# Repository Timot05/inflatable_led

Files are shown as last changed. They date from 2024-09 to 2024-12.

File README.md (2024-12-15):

# A portable light printed using Rapid Liquid Printing

## Specs

- 2700K
- About 400 lumens
- Dimmable
- Rechargeable
- Flashes when battery low

## Implementation

- Micro: RP2040
- LED Driver: TPS61165
- LED: OSRAM GW JTLPS1.EM-KKLL-XX58-1
- Batteries: TBD
- Battery charger: TBD

## TODOs for V1 order:

- Check order of LEDs
- Check the caps footprint
- C15, C16 are wrong size
- Remove todo from schematic

## TODOs for v2:

- [x] Add charging status to micro
- [x] fix the led circuit switching
- [x] enable low power mode with reset switch (no long press. How did we switch all circuits on mopi?)
- [x] Remove the cap on qspi_ss
- [x] DNP for the 3.3V led
- [x] Add a buck boost instead of ldo -> Remain with LDO but remove shotky diode (need to add it in case?)
- [x] Check the bat sense feature - probs ok
- [x] White circuit for reflection - will do
- [ ] Add gnd, vref, 3.3V to the debug port
- [x] Add the 10k resistor to the TS pin on the charger -> changed charger and fixed TS
- [x] Switch to ULDO
- [x] Change the battery holder -> changed to double battery holder

Nice to have:

- i2c connected charger
- Protrude the button more
- Nice feeling button

## TODOs for V3

- [ ] add a label for +/- battery
- [ ] remove the pullup on the on/off bt
- [ ] add a blinky led

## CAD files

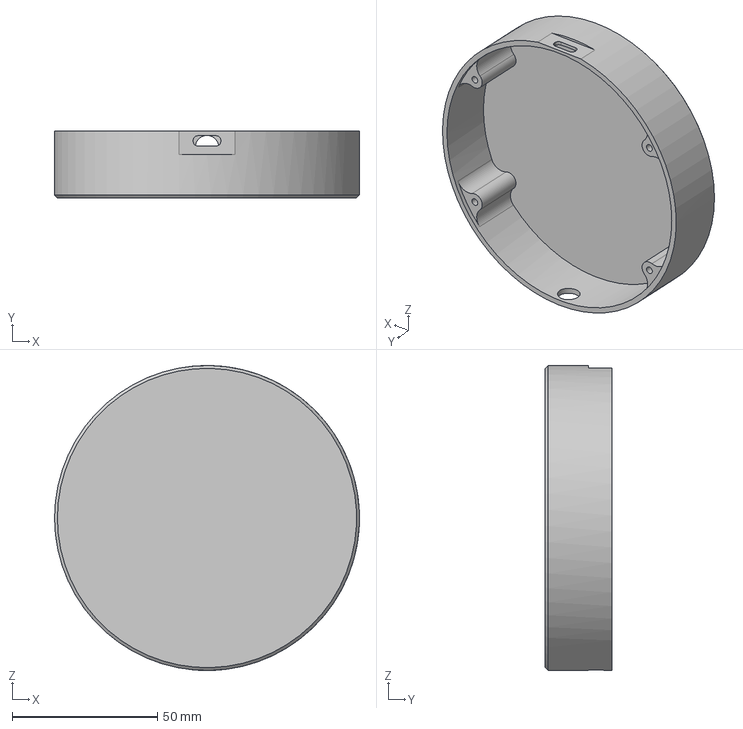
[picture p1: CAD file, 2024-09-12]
meca/Enclosure.step
105.0 x 23.0 x 105.0 mm

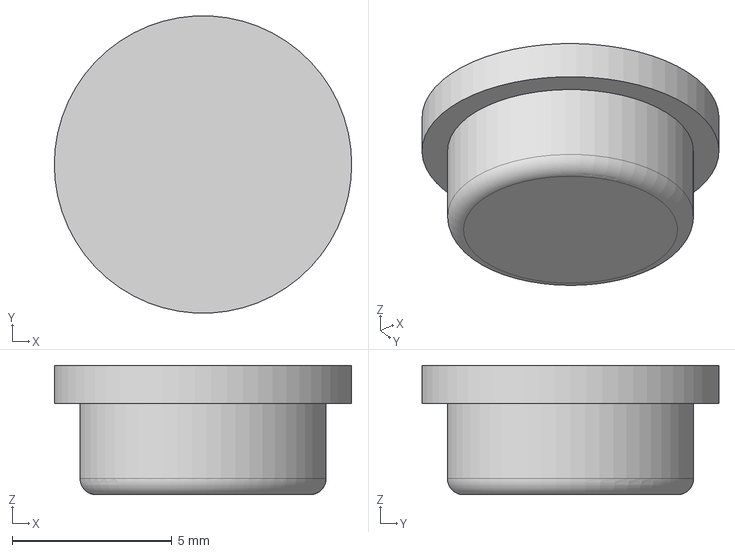
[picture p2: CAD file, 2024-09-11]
meca/Button.step
9.30 x 9.29 x 4.05 mm

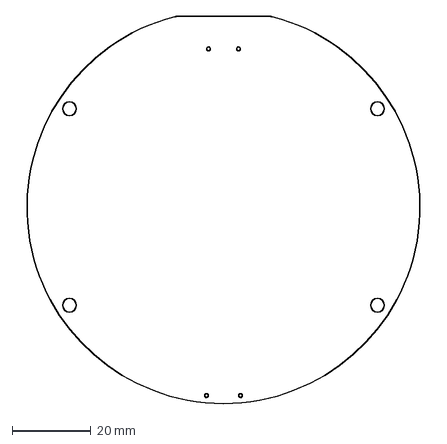
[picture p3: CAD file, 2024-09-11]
meca/PCB_outline.dxf
105.5 x 98.5 mm

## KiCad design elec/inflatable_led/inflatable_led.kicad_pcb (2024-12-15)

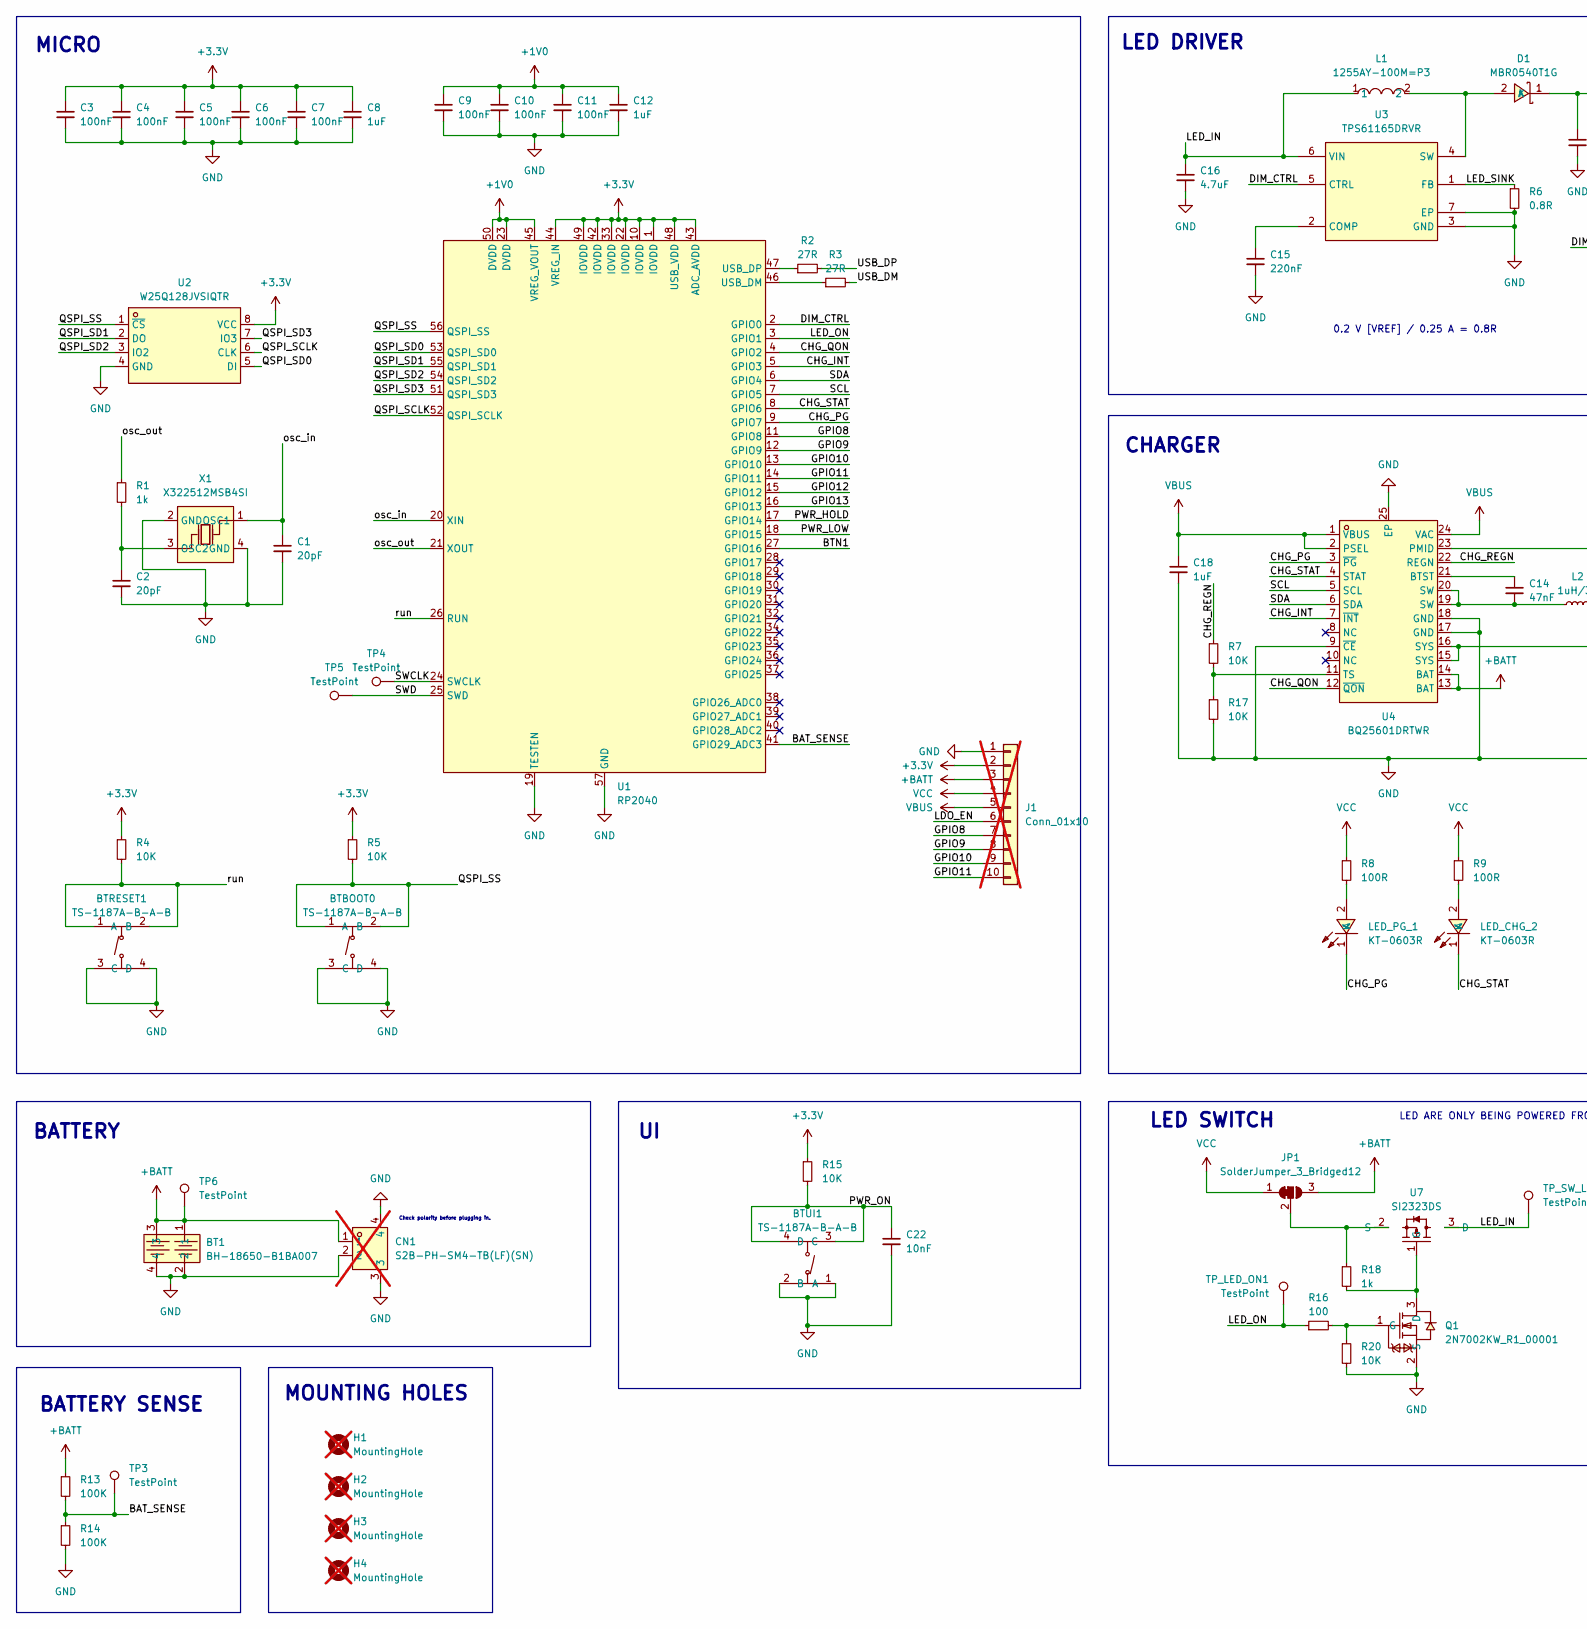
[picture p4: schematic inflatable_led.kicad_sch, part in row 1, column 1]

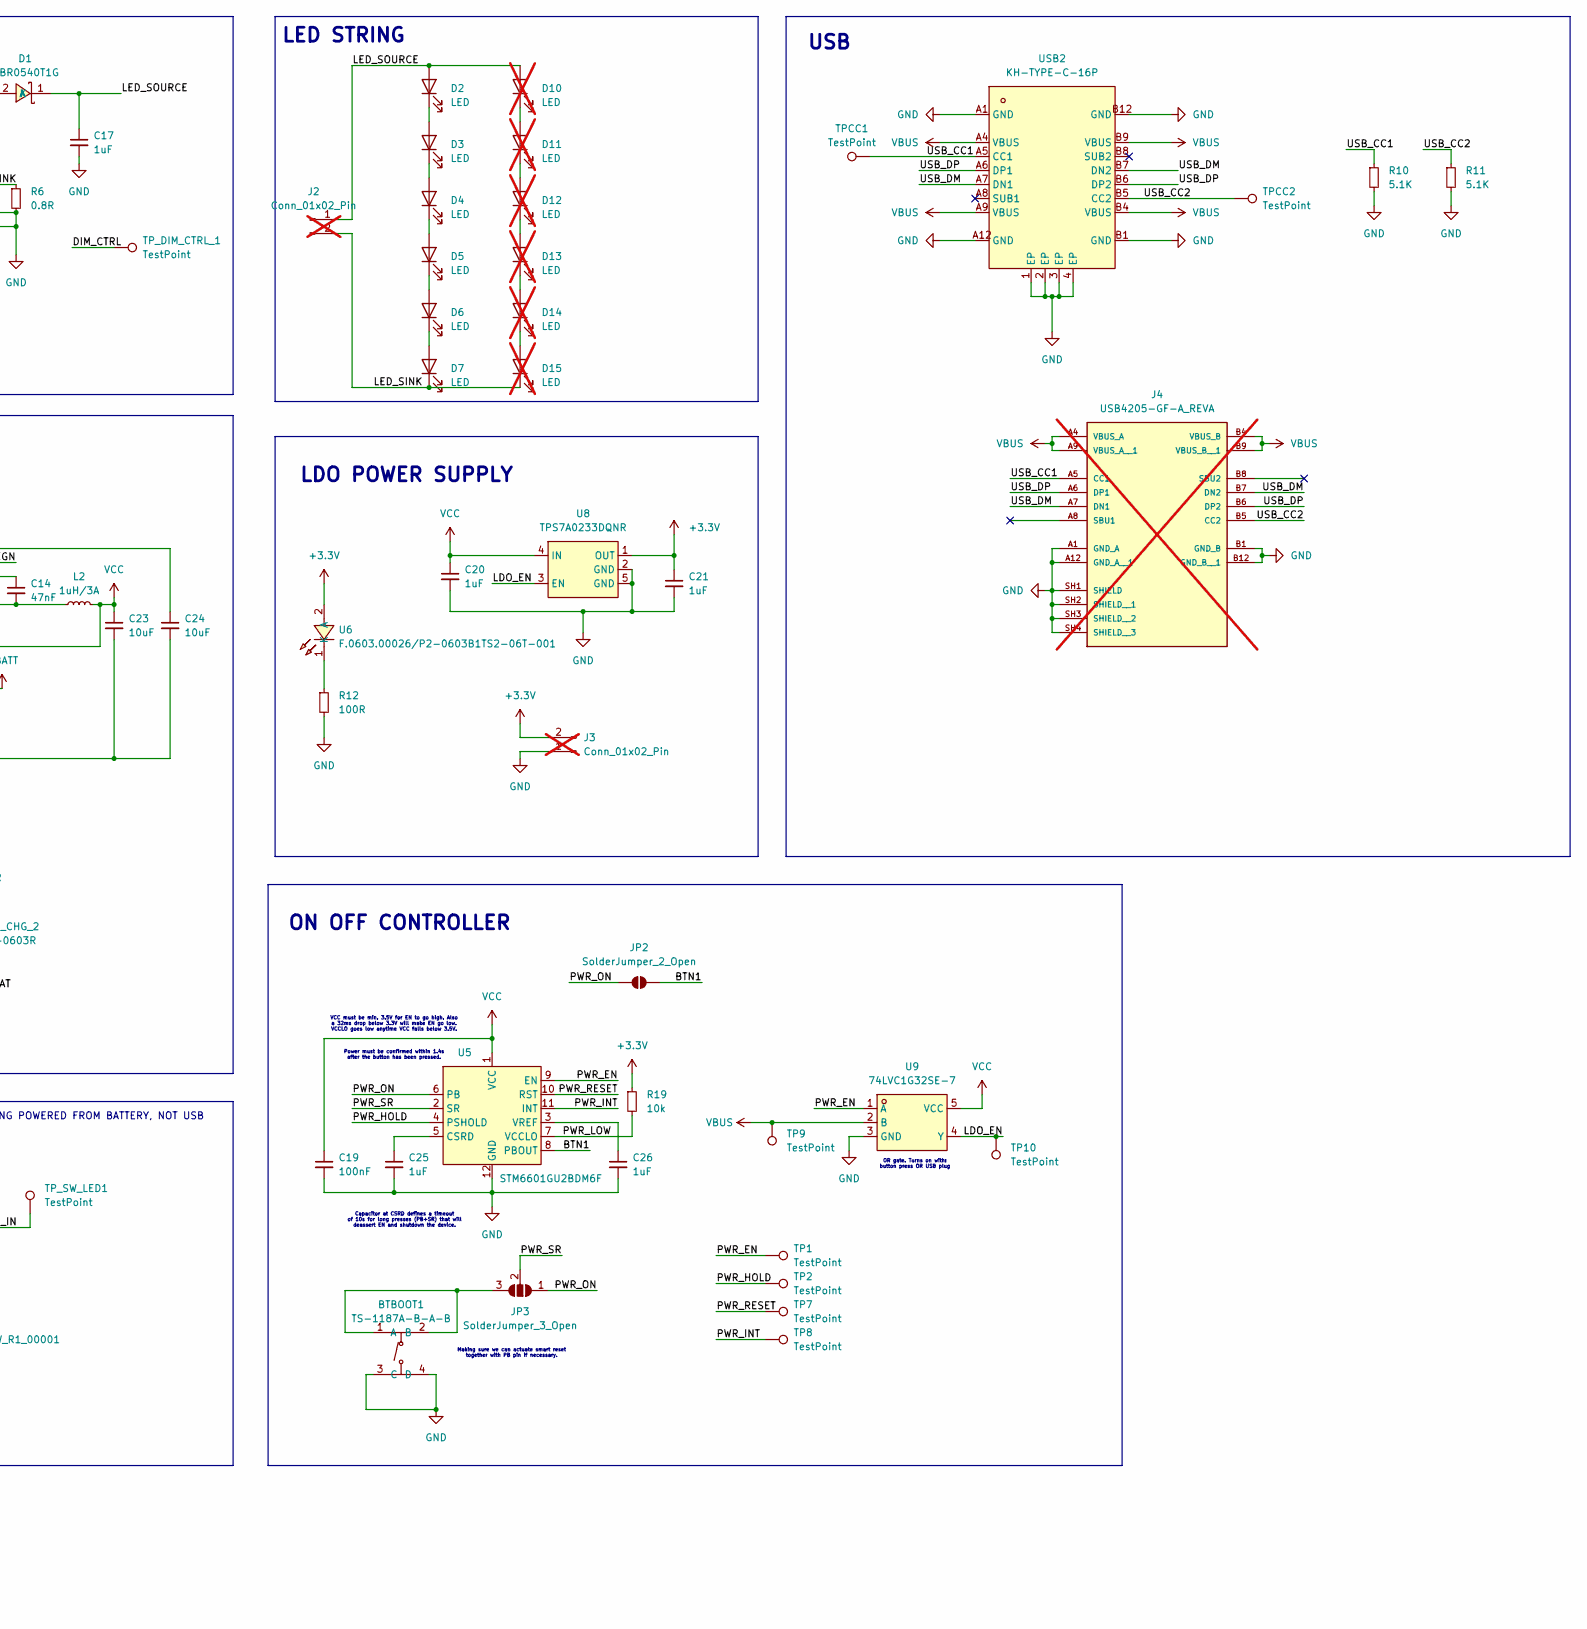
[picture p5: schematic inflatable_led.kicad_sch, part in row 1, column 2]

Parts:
BT1: BH-18650-B1BA007; BAT-SMD_BH-18650-B1BA007; LCSC Part C6937126
BTBOOT0, BTBOOT1: TS-1187A-B-A-B; SW-SMD_4P-L5.1-W5.1-P3.70-LS6.5-TL-2; LCSC Part C318884
BTRESET1: TS-1187A-B-A-B; SW-SMD_4P-L5.1-W5.1-P3.70-LS6.5-TL-2; LCSC Part C318884
BTUI1: TS-1187A-B-A-B; SW-SMD_4P-L5.1-W5.1-P3.70-LS6.5-TL-2; LCSC Part C318884
C1, C2: 20pF; C_0402_1005Metric; LCSC Part C1554
C3, C4, C5, C6, C7, C9, C10, C11: 100nF; C_0402_1005Metric; LCSC Part C1525
C8, C12, C17, C18, C20, C21: 1uF; C_0805_2012Metric; LCSC Part C28323
C14: 47nF; C_0402_1005Metric; Digikey 311-1801-1-ND
C15: 220nF; C_0402_1005Metric; LCSC Part C16772
C16: 4.7uF; C_0402_1005Metric; LCSC Part C23733
C19: 100nF; C_0402_1005Metric; Digikey 311-1776-1-ND
C22: 10nF; C_0402_1005Metric; LCSC Part C15195
C23, C24: 10uF; C_0805_2012Metric; LCSC Part C15850
C25, C26: 1uF; C_0805_2012Metric; Digikey 311-1444-1-ND
CN1: S2B-PH-SM4-TB(LF)(SN); CONN-SMD_P2.00_S2B-PH-SM4-TB-LF-SN; LCSC Part C295747; not fitted
D1: MBR0540T1G; SOD-123_L2.8-W1.8-LS3.7-RD; LCSC Part C109213
D2, D3, D4, D5, D6, D7: LED; GW JTLPS1EM; LCSC Part C5220764
D10: LED; GW JTLPS1EM; LCSC Part C5220764; not fitted
D11, D12, D13, D14, D15: LED; GW JTLPS1EM; not fitted
H1, H2, H3, H4: MountingHole; MountingHole_3.2mm_M3_Pad_Via; not fitted
J1: Conn_01x10; PinHeader_1x10_P1.00mm_Vertical; not fitted
J2, J3: Conn_01x02_Pin; PinHeader_1x02_P2.54mm_Vertical; not fitted
J4: USB4205-GF-A_REVA; GCT_USB4205-GF-A_REVA; PARTREV A; not fitted
JP1: SolderJumper_3_Bridged12; SolderJumper-3_P1.3mm_Bridged12_RoundedPad1.0x1.5mm
JP2: SolderJumper_2_Open; SolderJumper-2_P1.3mm_Open_TrianglePad1.0x1.5mm
JP3: SolderJumper_3_Open; SolderJumper-3_P2.0mm_Open_TrianglePad1.0x1.5mm
L1: 1255AY-100M=P3; IND-SMD_L6.0-W6.0; LCSC Part C160950
L2: 1uH/3A; L_1008_2520Metric; Digikey 1276-6929-1-ND
LED_CHG_2: KT-0603R; LED0603-RD; LCSC Part C2286
LED_PG_1: KT-0603R; LED0603-RD; LCSC Part C2286
Q1: 2N7002KW_R1_00001; SOT-323-3_L2.0-W1.3-P1.30-LS2.1-BR; LCSC Part C313495
R1, R18: 1k; R_0402_1005Metric; LCSC Part C11702
R2, R3: 27R; R_0402_1005Metric; LCSC Part C25100
R4, R5, R7, R15, R17, R20: 10K; R_0402_1005Metric; LCSC Part C25744
R6: 0.8R; R_0805_2012Metric_Pad1.20x1.40mm_HandSolder; LCSC Part C175720
R8, R9, R12: 100R; R_0402_1005Metric; LCSC Part C25076
R10, R11: 5.1K; R_0402_1005Metric; LCSC Part C25905
R13, R14: 100K; R_0402_1005Metric; LCSC Part C25741
R16: 100; R_0402_1005Metric; LCSC Part C25076
R19: 10k; R_0402_1005Metric; Digikey 311-10.0KHRCT-ND
TP1, TP2, TP7, TP8, TP9, TP10: TestPoint; TestPoint_Pad_D1.0mm
TP3, TP4, TP5, TP6: TestPoint; TestPoint_Pad_D1.5mm
TPCC1, TPCC2: TestPoint; TestPoint_Pad_D1.5mm
TP_DIM_CTRL_1: TestPoint; TestPoint_Pad_D1.5mm
TP_LED_ON1: TestPoint; TestPoint_Pad_D1.5mm
TP_SW_LED1: TestPoint; TestPoint_Pad_D1.5mm
U1: RP2040; LQFN-56_L7.0-W7.0-P0.4-EP; LCSC Part C2040
U2: W25Q128JVSIQTR; SOIC-8_L5.3-W5.3-P1.27-LS8.0-BL; LCSC Part C97521
U3: TPS61165DRVR; WSON-6_L2.0-W2.0-P0.65-TL-EP; LCSC Part C122568
U4: BQ25601DRTWR; WQFN-24_L4.0-W4.0-P0.50-TL-EP2.7; LCSC Part C2859691
U5: STM6601GU2BDM6F; TDFN-12_2x3mm_P0.5mm; Digikey 497-14857-1-ND
U6: F.0603.00026/P2-0603B1TS2-06T-001; LED0603-RD; LCSC Part C7496819
U7: SI2323DS; SOT-23-3_L2.9-W1.3-P1.90-LS2.4-BR; LCSC Part C5182044
U8: TPS7A0233DQNR; X2SON-4_L1.0-W1.0-P0.65-TL-EP; LCSC Part C5220177
U9: 74LVC1G32SE-7; SOT-353_L2.0-W1.2-P0.65-LS2.1-BL; LCSC Part C460530
USB2: KH-TYPE-C-16P; USB-C-SMD_KH-TYPE-C-16P; LCSC Part C709357
X1: X322512MSB4SI; OSC-SMD_4P-L3.2-W2.5-BL; LCSC Part C9002

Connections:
+1V0: C9.1, C10.1, C11.1, C12.1, U1.23 (DVDD), U1.45 (VREG_VOUT), U1.50 (DVDD)
+3.3V: C3.1, C4.1, C5.1, C6.1, C7.1, C8.1, C21.1, J1.2, J3.2, R4.1, R5.1, R15.1, R19.1, U1.1 (IOVDD), U1.10 (IOVDD), U1.22 (IOVDD), U1.33 (IOVDD), U1.42 (IOVDD), U1.43 (ADC_AVDD), U1.44 (VREG_IN), U1.48 (USB_VDD), U1.49 (IOVDD), U2.8 (VCC), U6.2 (A), U8.1 (OUT)
+BATT: BT1.1, BT1.3, CN1.1, J1.3, JP1.3 (B), R13.1, TP6.1, U4.13 (BAT), U4.14 (BAT)
/BAT_SENSE: R13.2, R14.1, TP3.1, U1.41 (GPIO29_ADC3)
/BTN1: JP2.2 (B), U1.27 (GPIO16), U5.8 (PBOUT)
/CHG_INT: U1.5 (GPIO3), U4.7 (~INT)
/CHG_PG: LED_PG_1.1 (K), U1.9 (GPIO7), U4.3 (~PG)
/CHG_QON: U1.4 (GPIO2), U4.12 (~QON)
/CHG_REGN: R7.1, U4.22 (REGN)
/CHG_STAT: LED_CHG_2.1 (K), U1.8 (GPIO6), U4.4 (STAT)
/DIM_CTRL: TP_DIM_CTRL_1.1, U1.2 (GPIO0), U3.5 (CTRL)
/GPIO8: J1.7, U1.11 (GPIO8)
/GPIO9: J1.8, U1.12 (GPIO9)
/GPIO10: J1.9, U1.13 (GPIO10)
/GPIO11: J1.10, U1.14 (GPIO11)
/GPIO12: U1.15 (GPIO12)
/GPIO13: U1.16 (GPIO13)
/LDO_EN: J1.6, TP10.1, U8.3 (EN), U9.4 (Y)
/LED_IN: C16.1, L1.1, TP_SW_LED1.1, U3.6 (VIN), U7.3 (D)
/LED_ON: R16.1, TP_LED_ON1.1, U1.3 (GPIO1)
/LED_SINK: D7.1 (K), D15.1 (K), J2.2, R6.1, U3.1 (FB)
/LED_SOURCE: C17.1, D1.1 (K), D2.2 (A), D10.2 (A), J2.1
/PWR_EN: TP1.1, U5.9 (EN), U9.1 (A)
/PWR_HOLD: TP2.1, U1.17 (GPIO14), U5.4 (PSHOLD)
/PWR_INT: TP8.1, U5.11 (INT)
/PWR_LOW: R19.2, U1.18 (GPIO15), U5.7 (VCCLO)
/PWR_ON: BTUI1.3 (C), BTUI1.4 (D), C22.1, JP2.1 (A), JP3.1 (A), R15.2, U5.6 (PB)
/PWR_RESET: TP7.1, U5.10 (RST)
/PWR_SR: JP3.2 (C), U5.2 (SR)
/QSPI_SCLK: U1.52 (QSPI_SCLK), U2.6 (CLK)
/QSPI_SD0: U1.53 (QSPI_SD0), U2.5 (DI)
/QSPI_SD1: U1.55 (QSPI_SD1), U2.2 (DO)
/QSPI_SD2: U1.54 (QSPI_SD2), U2.3 (IO2)
/QSPI_SD3: U1.51 (QSPI_SD3), U2.7 (IO3)
/QSPI_SS: BTBOOT0.1 (A), BTBOOT0.2 (B), R5.2, U1.56 (QSPI_SS), U2.1 (~CS)
/SCL: U1.7 (GPIO5), U4.5 (SCL)
/SDA: U1.6 (GPIO4), U4.6 (SDA)
/SWCLK: TP4.1, U1.24 (SWCLK)
/SWD: TP5.1, U1.25 (SWD)
/USB_CC1: J4.A5 (CC1), R10.1, TPCC1.1, USB2.A5 (CC1)
/USB_CC2: J4.B5 (CC2), R11.1, TPCC2.1, USB2.B5 (CC2)
/USB_DM: J4.A7 (DN1), J4.B7 (DN2), R3.2, USB2.A7 (DN1), USB2.B7 (DN2)
/USB_DP: J4.A6 (DP1), J4.B6 (DP2), R2.2, USB2.A6 (DP1), USB2.B6 (DP2)
/osc_in: C1.1, U1.20 (XIN), X1.1 (OSC1)
/osc_out: R1.1, U1.21 (XOUT)
/run: BTRESET1.1 (A), BTRESET1.2 (B), R4.2, U1.26 (RUN)
GND: BT1.2, BT1.4, BTBOOT0.3 (C), BTBOOT0.4 (D), BTBOOT1.3 (C), BTBOOT1.4 (D), BTRESET1.3 (C), BTRESET1.4 (D), BTUI1.1 (A), BTUI1.2 (B), C1.2, C2.2, C3.2, C4.2, C5.2, C6.2, C7.2, C8.2, C9.2, C10.2, C11.2, C12.2, C15.2, C16.2, C17.2, C18.2, C19.2, C20.2, C21.2, C22.2, C23.2, C24.2, C25.2, C26.2, CN1.2, CN1.3, CN1.4, J1.1, J3.1, J4.A1 (GND_A), J4.A12 (GND_A__1), J4.B1 (GND_B), J4.B12 (GND_B__1), J4.SH1 (SHIELD), J4.SH2 (SHIELD__1), J4.SH3 (SHIELD__2), J4.SH4 (SHIELD__3), Q1.2 (S), R6.2, R10.2, R11.2, R12.2, R14.2, R17.2, R20.2, U1.19 (TESTEN), U1.57 (GND), U2.4 (GND), U3.3 (GND), U3.7 (EP), U4.9 (~CE), U4.17 (GND), U4.18 (GND), U4.25 (EP), U5.12 (GND), U8.2 (GND), U8.5 (GND), U9.3 (GND), USB2.1 (EP), USB2.2 (EP), USB2.3 (EP), USB2.4 (EP), USB2.A1 (GND), USB2.A12 (GND), USB2.B1 (GND), USB2.B12 (GND), X1.2 (GND), X1.4 (GND)
unnamed: BTBOOT1.1 (A), BTBOOT1.2 (B), JP3.3 (B)
unnamed: C14.2, L2.1, U4.19 (SW), U4.20 (SW)
unnamed: D1.2 (A), L1.2, U3.4 (SW)
unnamed: D2.1 (K), D3.2 (A)
unnamed: D3.1 (K), D4.2 (A)
unnamed: D4.1 (K), D5.2 (A)
unnamed: D5.1 (K), D6.2 (A)
unnamed: D6.1 (K), D7.2 (A)
unnamed: D10.1 (K), D11.2 (A)
unnamed: D11.1 (K), D12.2 (A)
unnamed: D12.1 (K), D13.2 (A)
unnamed: D13.1 (K), D14.2 (A)
unnamed: D14.1 (K), D15.2 (A)
unnamed: JP1.2 (C), R18.1, U7.2 (S)
unnamed: LED_CHG_2.2 (A), R9.2
unnamed: LED_PG_1.2 (A), R8.2
unnamed: Q1.3 (D), R18.2, U7.1 (G)
unnamed: Q1.1 (G), R16.2, R20.1
unnamed: R3.1, U1.46 (USB_DM)
unnamed: R2.1, U1.47 (USB_DP)
unnamed: C15.1, U3.2 (COMP)
unnamed: C14.1, U4.21 (BTST)
unnamed: C24.1, U4.23 (PMID)
unnamed: R7.2, R17.1, U4.11 (TS)
unnamed: C25.1, U5.5 (CSRD)
unnamed: C26.1, U5.3 (VREF)
unnamed: R12.1, U6.1 (K)
unnamed: C2.1, R1.2, X1.3 (OSC2)
VBUS: C18.1, J1.5, J4.A4 (VBUS_A), J4.A9 (VBUS_A__1), J4.B4 (VBUS_B), J4.B9 (VBUS_B__1), TP9.1, U4.1 (VBUS), U4.2 (PSEL), U4.24 (VAC), U9.2 (B), USB2.A4 (VBUS), USB2.A9 (VBUS), USB2.B4 (VBUS), USB2.B9 (VBUS)
VCC: C19.1, C20.1, C23.1, J1.4, JP1.1 (A), L2.2, R8.1, R9.1, U4.15 (SYS), U4.16 (SYS), U5.1 (VCC), U8.4 (IN), U9.5 (VCC)

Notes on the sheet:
OR gate. Turns on with: button press OR USB plug
VCC must be min. 3.5V for EN to go high. Also a 32ms drop below 3.3V will make EN go low. VCCLO goes low anytime VCC falls below 3.5V. Power must be confirmed within 1.4s after the button has been pressed.
Capacitor at CSRD defines a timeout of 10s for long presses (PB+SR) that will deassert EN and shutdown the device.
LED ARE ONLY BEING POWERED FROM BATTERY, NOT USB
Check polarity before plugging in.
Making sure we can actuate smart reset together with PB pin if necessary.
BATTERY
0.2 V [VREF] / 0.25 A = 0.8R
LED SWITCH
LED STRING
MOUNTING HOLES
ON OFF CONTROLLER
CHARGER
LDO POWER SUPPLY
LED DRIVER
USB
BATTERY SENSE
MICRO

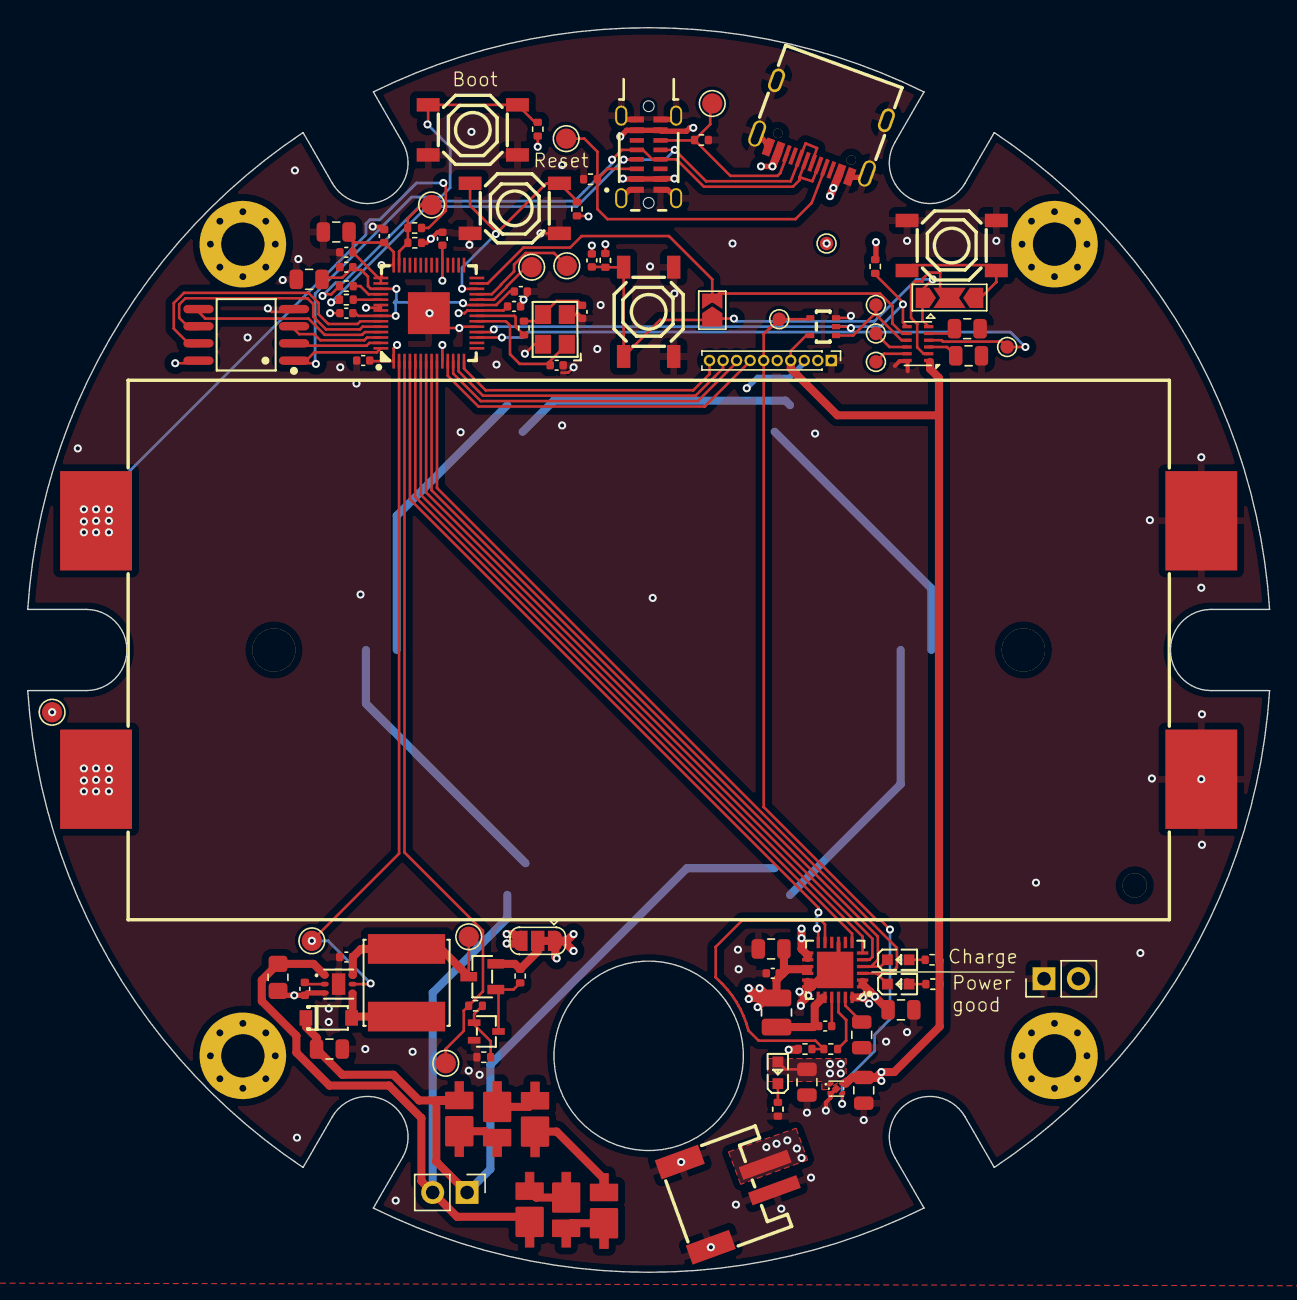
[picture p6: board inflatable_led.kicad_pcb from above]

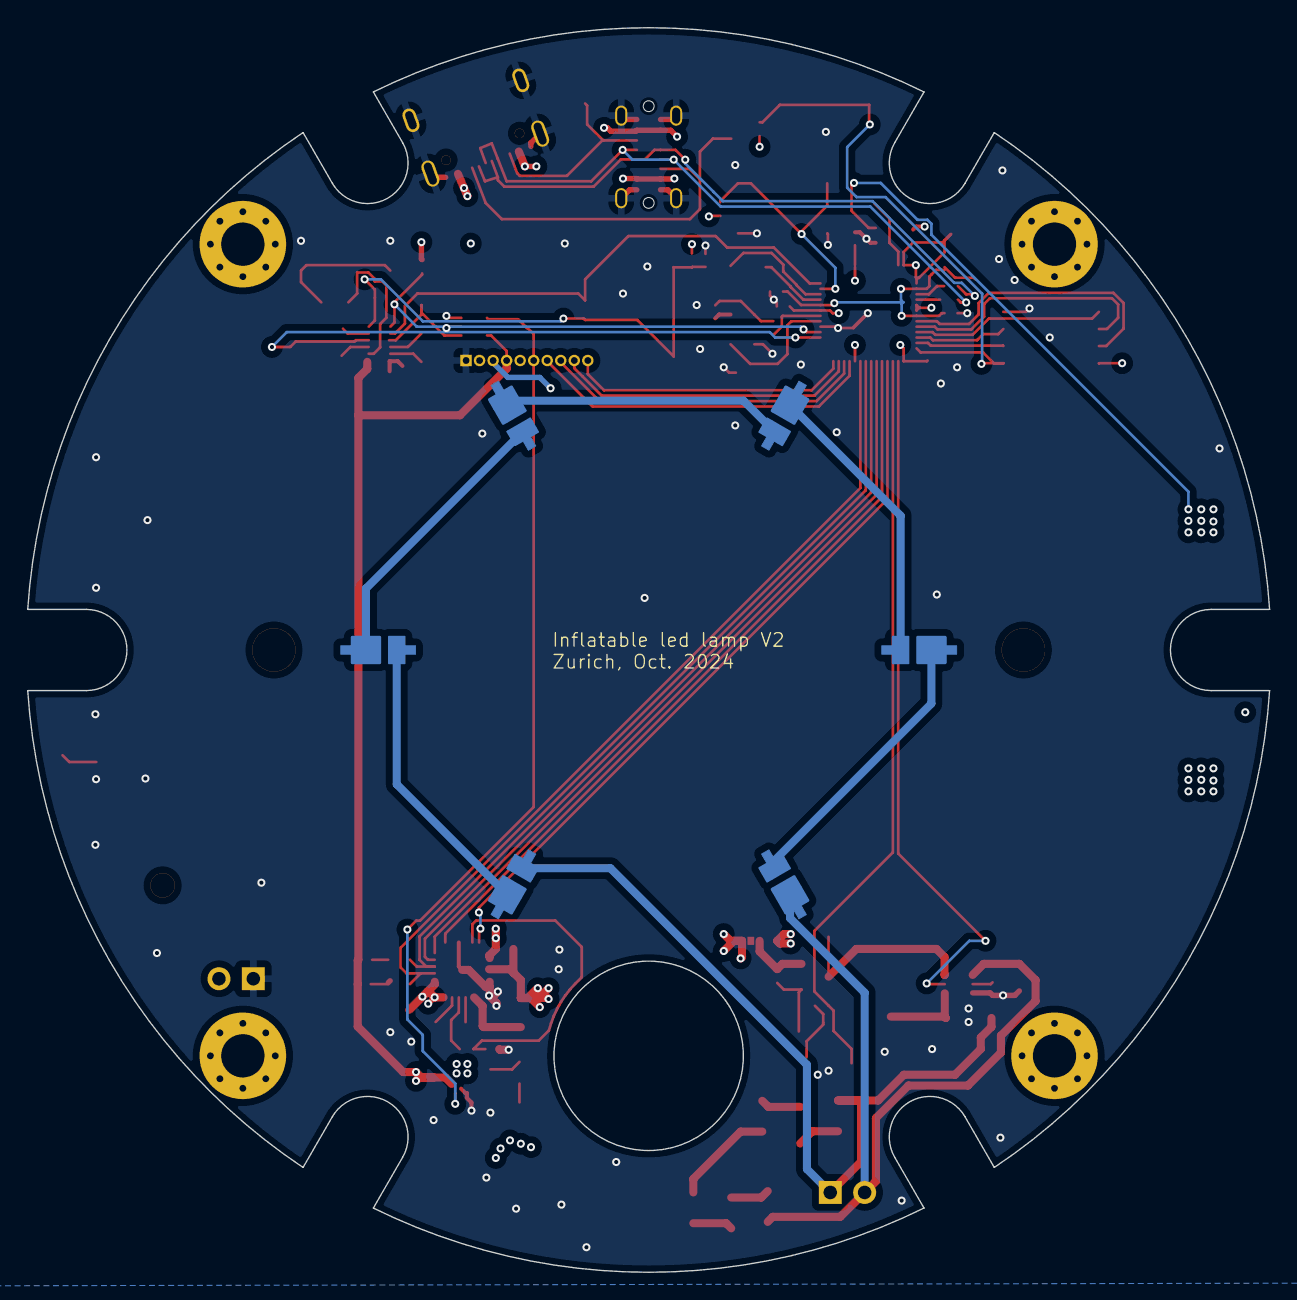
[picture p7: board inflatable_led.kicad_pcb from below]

Board: 4 copper layers, 91.8 x 92.0 mm, 106 parts (6 on the bottom side), 75 nets.

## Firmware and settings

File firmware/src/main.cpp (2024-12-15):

#include <Arduino.h>
#include "main.h"

#include "pico/stdlib.h"
#include "hardware/pwm.h"

#include "../lib/StateMachine/StateMachine.hpp"
#include "../lib/StateMachine/State.hpp"

#include "../lib/bq25601/bq25601.h"

#define PRINT_DEBUG 0

unsigned long lastPressTime = 0;      // Last time the button was pressed

const unsigned long shortPressDuration = 1000;

StateMachine state_machine;
State state;

unsigned int brightness = 1;

uint slice_num;

void handleButtonPress() {
    lastPressTime = millis();
}

void handleButtonRelease() {
    unsigned long currentTime = millis();
    unsigned long pressDuration = currentTime - lastPressTime;

    if (2 < pressDuration < shortPressDuration) {
        state_machine.shortPress();
    }
}

void handleButtonChange() {
    if (digitalRead(BTN_1_PIN) == LOW) {
        handleButtonPress();
    } else {
        handleButtonRelease();
    }
}

// int is active low
bool chr_int = false;
void handleChgInt() {
    chr_int = true;
}


void setup() {
    #if PRINT_DEBUG
    Serial1.begin(115200); // USB serial
    Serial2.setTX(8); // Set TX to GPIO10
    Serial2.setRX(9); // Set RX to GPIO11
    Serial2.begin(115200); // UART serial
    #endif

    pinMode(CHG_STAT_PIN, INPUT);
    pinMode(CHG_PG_PIN, INPUT);
    pinMode(CHG_INT_PIN, INPUT_PULLUP);
    attachInterrupt(digitalPinToInterrupt(CHG_INT_PIN), handleChgInt, FALLING);
    pinMode(CHG_SDA_PIN, INPUT_PULLUP);
    pinMode(CHG_SCL_PIN, INPUT_PULLUP);

    pinMode(CHG_QON_PIN, OUTPUT);
    digitalWrite(CHG_QON_PIN, HIGH);

    // Setup the led pins
    pinMode(LED_ON_PIN, OUTPUT);
    pinMode(LED_DIM_CTRL_PIN, OUTPUT);

    pinMode(BTN_1_PIN, INPUT_PULLUP);

    // delay(20);
    // Power hold at startup
    pinMode(PWR_HOLD, OUTPUT);
    digitalWrite(PWR_HOLD, HIGH);

    attachInterrupt(digitalPinToInterrupt(BTN_1_PIN), handleButtonChange, CHANGE);

    digitalWrite(LED_ON_PIN, HIGH);

    gpio_set_function(LED_DIM_CTRL_PIN, GPIO_FUNC_PWM);
    slice_num = pwm_gpio_to_slice_num(LED_DIM_CTRL_PIN);
    pwm_set_wrap(slice_num, 12499);


    if(!bq25601_init()) {
        #if PRINT_DEBUG
        Serial.println("Charger init failed!");
        #endif
        bq25601_writeRegister(REG00, 0b00010111);
    }
}

#define BR_1 1
#define BR_2 50
#define BR_3 255

void loop() {
    unsigned long currentTime = millis();

    state = state_machine.getState();

    #if PRINT_DEBUG
    void debugPrint(const char* stateName) {
        Serial.println(stateName);
        Serial2.println(stateName);
    }
    #endif

    switch (state) {
        case State::OFF:
            #if PRINT_DEBUG
            debugPrint("OFF");
            #endif
            digitalWrite(PWR_HOLD, LOW);
            break;

        case State::ON_1:
        case State::ON_2:
        case State::ON_3: {
            #if PRINT_DEBUG
            if (state == State::ON_1) debugPrint("ON_1");
            else if (state == State::ON_2) debugPrint("ON_2");
            else debugPrint("ON_3");
            #endif

            uint8_t brightness = (state == State::ON_1) ? BR_1 :
                                (state == State::ON_2) ? BR_2 : BR_3;

            unsigned int value = map(brightness, 0, 255, 0, 12499);
            pwm_set_chan_level(slice_num, PWM_CHAN_A, value);
            pwm_set_enabled(slice_num, true);
            break;
        }

        case State::CHARGING:
            #if PRINT_DEBUG
            debugPrint("CHARGING");
            #endif
            digitalWrite(PWR_HOLD, LOW);
            digitalWrite(LED_ON_PIN, LOW);
            break;

        default:
            #if PRINT_DEBUG
            debugPrint("UNKNOWN");
            #endif
            break;
    }

    if (digitalRead(BTN_1_PIN) == LOW && shortPressDuration < currentTime - lastPressTime) {
        state_machine.longPress();
    }

    // Handle charger states
    // if (chr_int) {
    //     Serial2.println("Charger interrupt");
    //     Serial2.print("Previous message: ");
    //     Serial2.println(bq25601_readRegister(REG09), BIN);
    //     Serial2.print("Current message: ");
    //     Serial2.println(bq25601_readRegister(REG09), BIN);
    //     chr_int = false;
    // }

    // Serial2.println("Charger interrupt");
    // Serial2.print("Previous message: ");
    // Serial2.println(bq25601_readRegister(REG02), BIN);
    // Serial2.print("Current message: ");
    // Serial2.println(bq25601_readRegister(REG02), BIN);

    bq2501_updateStatus();
    if (bq2501_get_vbus() != NO_INPUT) {
        if (bq2501_get_chrg() == PRE_CHARGE1 || bq2501_get_chrg() == FAST_CHARGE) {
            state_machine.charging();
        }
        else if (bq2501_get_chrg() == CHARGE_DONE) {
            state_machine.charged();
        }
        else {
            state_machine.error();
        }
    }
    else {
        state_machine.not_plugged();
    }

    delay(50);
}

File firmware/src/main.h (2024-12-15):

#define LED_DIM_CTRL_PIN 0
#define LED_ON_PIN 1
#define CHG_QON_PIN 2
#define CHG_INT_PIN 3
#define CHG_SDA_PIN 4
#define CHG_SCL_PIN 5
#define CHG_STAT_PIN 6
#define CHG_PG_PIN 7
#define RST_PIN 11
#define PWR_HOLD 14
#define BTN_1_PIN 16

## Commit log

2024-08-22 add micro
    [inflatable_led.kicad_pcb, inflatable_led.kicad_sch]
2024-09-01 progress on schematic
    [inflatable_led.kicad_sch]
2024-09-05 checking schematic
    [inflatable_led.kicad_pcb, inflatable_led.kicad_sch]
2024-09-11 layout almost done + CI
    [PCB_outline.dxf, inflatable_led.kicad_pcb, inflatable_led.kicad_sch]
2024-09-11 fix all unconnected items
    [inflatable_led.kicad_pcb]
2024-09-11 change layout
    [inflatable_led.kicad_pcb]
2024-09-11 add 3D files
    [Button.step, Enclosure.step]
2024-09-11 add all part numbers
    [inflatable_led.kicad_sch]
2024-09-11 fix cpl file
    [inflatable_led.kicad_pcb, inflatable_led.kicad_sch]
2024-09-11 exclude from pos file
    [inflatable_led.kicad_pcb]
2024-09-12 fix footprint + add pn
    [inflatable_led.kicad_pcb, inflatable_led.kicad_sch]
2024-09-12 fix more footprints
    [inflatable_led.kicad_pcb, inflatable_led.kicad_sch]
2024-09-12 leds in the wrong order
    [inflatable_led.kicad_pcb, inflatable_led.kicad_sch]
2024-09-12 add updated enclosure
    [Enclosure.step]
2024-09-26 fix missing 3.3V on flash
    [inflatable_led.kicad_sch]
2024-09-28 v1 is working, add v2 requests
    [inflatable_led.kicad_pcb, inflatable_led.kicad_sch]
2024-09-28 minor schematic changes
    [inflatable_led.kicad_sch]
2024-09-29 fix lower light limit
    [main.cpp]
2024-10-14 whole new circuit
    [inflatable_led.kicad_pcb, inflatable_led.kicad_sch]
2024-10-14 update bom
    [inflatable_led.kicad_pcb, inflatable_led.kicad_sch]
2024-10-14 fix additional parts in BOM
    [inflatable_led.kicad_pcb, inflatable_led.kicad_sch]
2024-10-14 final tweaks
    [inflatable_led.kicad_pcb, inflatable_led.kicad_sch]
2024-10-15 dnp battery conn
    [inflatable_led.kicad_pcb, inflatable_led.kicad_sch]
2024-10-15 add a few silkscreen items
    [inflatable_led.kicad_pcb]
2024-10-15 add OR gate to circuit
    [inflatable_led.kicad_pcb, inflatable_led.kicad_sch, simulation.kicad_pcb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]
2024-12-15 project is working
    [inflatable_led.kicad_pcb]
